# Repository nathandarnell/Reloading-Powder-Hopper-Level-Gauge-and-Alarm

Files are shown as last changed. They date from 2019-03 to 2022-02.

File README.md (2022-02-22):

# Reloading Powder Hopper Level Gauge and Alarm

This was inspired by a video by Farrow Tech: [https://www.youtube.com/watch?v=m2Si6LQx2WA](https://www.youtube.com/watch?v=m2Si6LQx2WA).  The demonstration it is about two years old and I haven't seen anything else like it so I decided to make my own version.  

## Hardware
My version uses an ESP8266 NodeMCU, a ST7735S TFT display, a VL6180X time of flight sensor, a rotary encoder, and some various hardware.
  * [NodeMCU ESP8266](https://www.ebay.com/itm/NodeMCU-Lua-ESP8266-ESP-12E-cp2102-Arduino-compatible-wifi-development-board/123866319935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) - The case is designed to fit this particular board. If you use a different size/shape board or one with different pin definitions it may not work correctly. The two main versions of these boards have either a CP2102 or CH340G chip. The CP2102 boards are narrower and what fits in this case so make sure you buy one of those!
  * [1.77" TFT Screen](https://www.ebay.com/itm/1-77-inch-1-8-TFT-Color-Display-Module-Breakout-SPI-ST7735S-for-Arduino-UNO-LCD/222565215470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) - This particular screen seems to be sold very widely and if you use the same pins to wire it and use the same settings in User_Setup.h for the TFT_eSPI library, it should work fine
  * [VL6180X Time-of-Flight Sensor](https://www.ebay.com/itm/For-Arduino-I2C-Gesture-Recognition-Range-Finder-Optical-Sensor-Module-VL6180X/302991764658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) - The Adafruit version of this sensor also seems to work correctly but is about 2x the cost
  * [Rotary Encoder](https://www.amazon.com/gp/product/B07BN3DGBS/ref=ppx_yo_dt_b_asin_title_o02_s00?ie=UTF8&psc=1) - See below for notes on what rotary encoders work well
  * [Buzzer](https://www.amazon.com/gp/product/B07VSHHFKJ/ref=ppx_yo_dt_b_search_asin_title?ie=UTF8&psc=1) - Optional buzzer if you want an audible cue that when the powder is low
  * 6 M3 nuts
  * 2 M2.5 nuts
  * 6 M3 x 10 screws
  * 2 M2.5 x 10 screws
  
## Libraries and firware.bin
While Farrow Tech was able to make it without libraries, mine uses:
  * [ArduinoMenu](https://github.com/neu-rah/ArduinoMenu)
  * [streamFlow](https://github.com/neu-rah/streamFlow)
  * [TFT_eSPI](https://github.com/Bodmer/TFT_eSPI) - You will have to setup your TFT settings in the User_Setup.h file.  I have included mine if you would like to copy it into the TFT_eSPI library folder.  If you use the library I included it is already correct
  * [VL6180X](https://github.com/pololu/vl6180x-arduino)
  * [ClickEncoder](https://github.com/soligen2010/encoder) - This is a fork of the rotary encoder library ArduinoMenu uses by default and has some updates over the original
  * [ardunoWebSockets](https://github.com/Links2004/arduinoWebSockets) - This library is needed by newer versions of ArduinoMenu even though it doesn't do anything for this program
  
### Adruino IDE esp8266 Board Version
As per [the comment from dandekalb](https://www.thingiverse.com/thing:3485453/comments#comment-6370874), you will get compile errors from the Arduino IDE if you have the board version set above 2.7.3.  This has not been tested on VS Code with PlatformIO but it is safe to assume the same.

To change the board version in Arduino IDE:

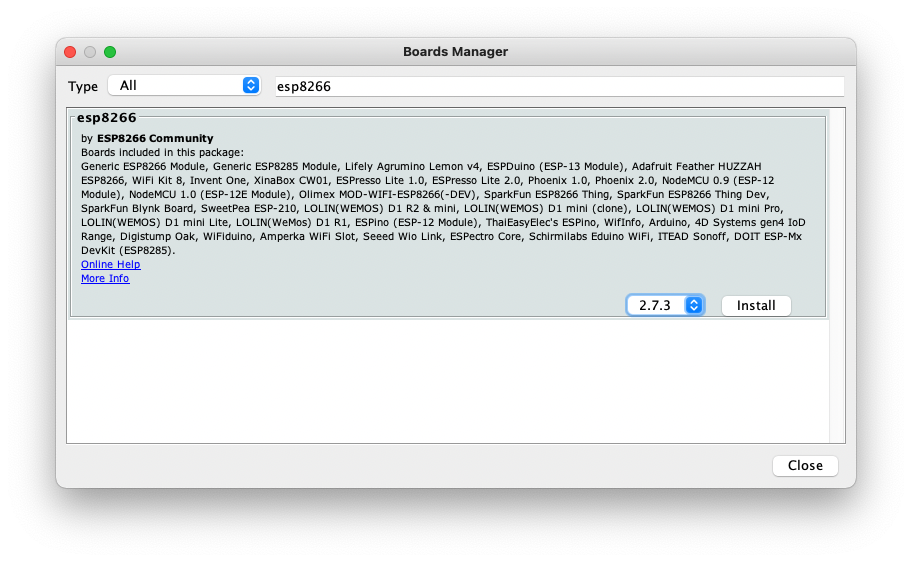
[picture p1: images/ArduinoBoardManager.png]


To change the board version in PlatformIO (this has not been tested but should work): 

In your platformi.ini replace

`platform = espressif8266`

with

`platform = espressif8266@2.7.3`

### Importing Libraries
Because some of the libraries (mostly ArduinoMenu) are under active development, I have downloaded the versions that work currently (9/4/2019) as zip files for importing into Arduino IDE or PlatformIO.  For Arduino there is a import a zip file to library menu option.  For PlatformIO with VS Code extract the zip files to the include folder within the project folder.  

### firmware.bin
If you are running into problems and have all of the wiring done like described in PowderHopperGauge.ino, I also uploaded a firmware.bin file that can be uploaded with [nodemcu-pyflasher](https://github.com/marcelstoer/nodemcu-pyflasher/releases) without the need to import libraries or compile anything yourself.  If you make changes to your wiring however, you will need to compile the program and the firmware.bin file will not work for you.

New for this version is the inclusion of the serial interface.  If you are having issues with the click encoder rotations not registering but the clicks are working, you can use the serial interface to navigate the ArduinoMenu options.

## Rotary Encoders
The most difficult troubleshooting seems to be with rotary encoders.  I have tried four different kinds and have found success with two of them.  There are two seperate issues that have come up: how the rotary encoder counts pulses and how the circuit uses pullups and capacitors.
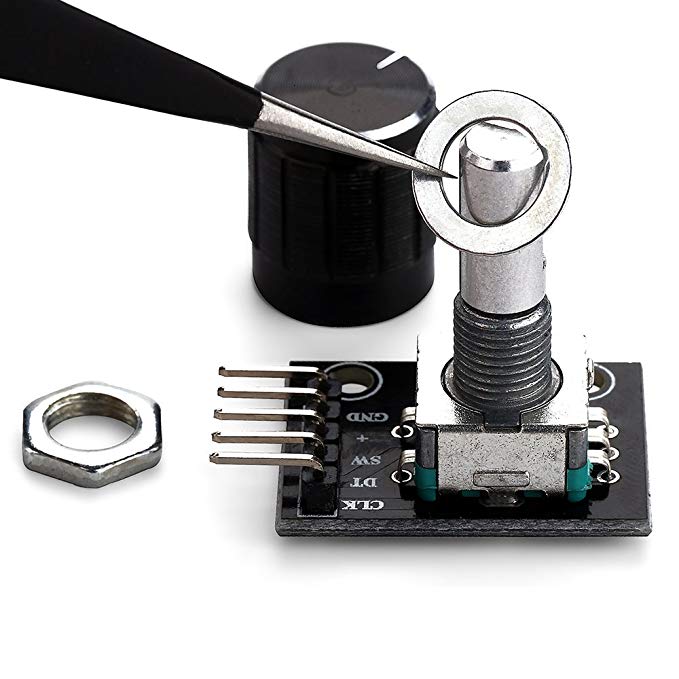
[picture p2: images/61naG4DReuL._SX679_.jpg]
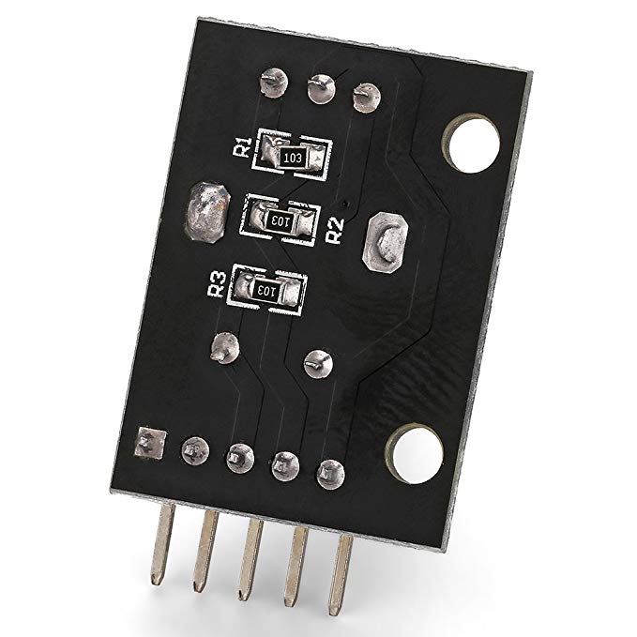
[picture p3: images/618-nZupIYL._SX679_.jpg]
  *  [Amazon 6 pack](https://www.amazon.com/gp/product/B07BN3DGBS/ref=ppx_yo_dt_b_asin_title_o02_s00?ie=UTF8&psc=1) - These have pullup resistors on the button and on the rotary encoder and mostly worked correctly.  Out of the six I received one did not work at all and one had at least a single deadspot that didn't register rotations.  Otherwise the price and consistancy has been good.
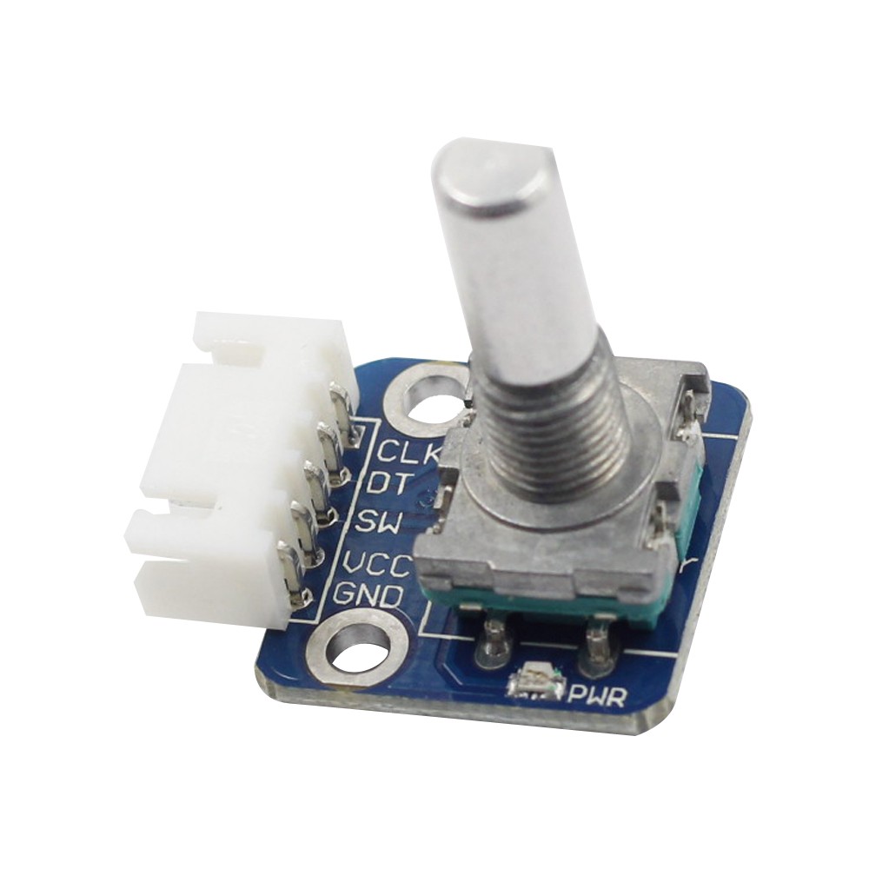
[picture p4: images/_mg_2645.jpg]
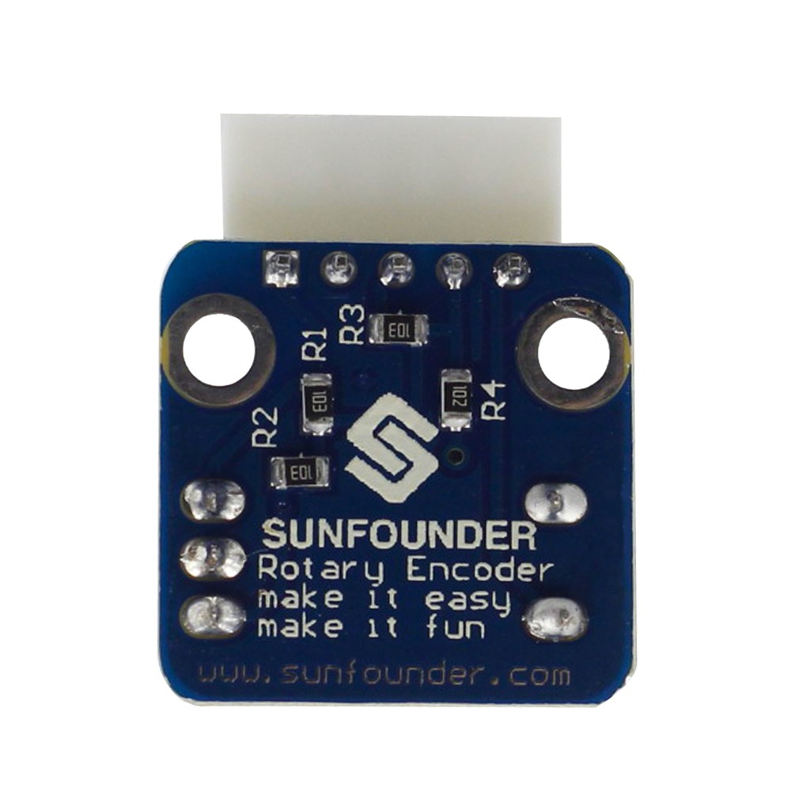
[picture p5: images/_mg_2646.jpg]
  *  [Sunfounder Rotary Encoder](https://www.sunfounder.com/rotary-encoder-module.html) - These also have pullups on all the pins as well as a LED so you can tell when it's powered on.  These are the most expensive option ($6.99 each) but the quality of the encoder and the board is very good.
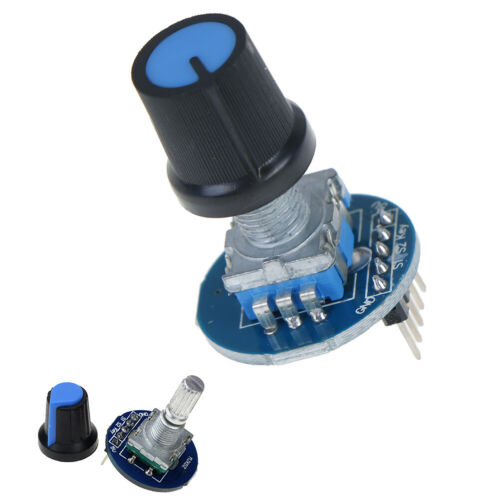
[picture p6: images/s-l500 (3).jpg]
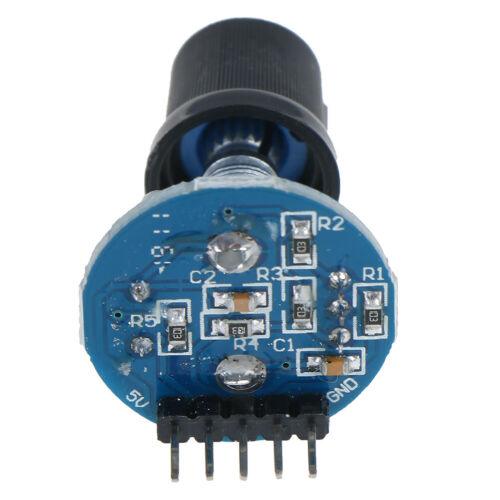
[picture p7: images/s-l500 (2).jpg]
  *  [Round PCB with capacitors for 5V](https://www.ebay.com/itm/Rotary-encoder-module-brick-sensor-development-audio-potentiometer-knob-SKUS/233308683253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) - These seem like a great option since they have capacitors for debouncing but they only work correctly with 5V and will not work at 3.3V.  They seem easy to distinguish since the power pins are labeled "5V" and not "VIN" or "+" like the others here.  And they are round.  I haven't seen any that look like this one that do not say "5V" on them so I would steer clear.
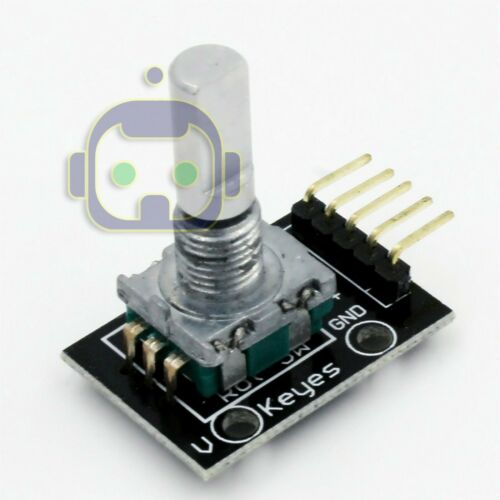
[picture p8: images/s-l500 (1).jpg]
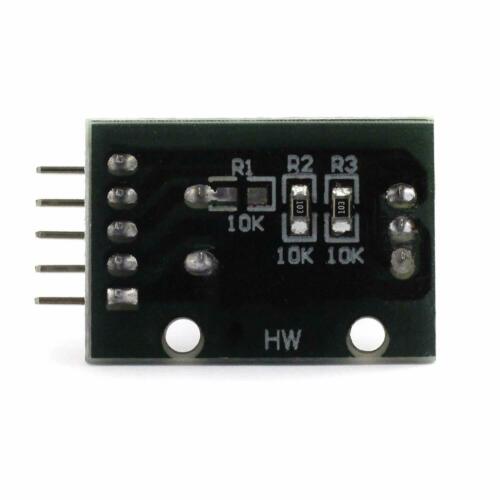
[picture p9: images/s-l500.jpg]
  *  [Half step wth no switch pullup](https://www.ebay.com/itm/2X-Rotary-Encoder-Digital-Potentiometer-20mm-Knurled-Shaft-with-Switch-USA/382606587878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) - This one has two issues: the switch doesn't have pullups on it like the others above but the deal breaker is that the rotary encoder outputs half the pulses of the other models.  Each "click" moves both pins to high or both pins to low.  The others move both pins to low and high on every "click."

## Rotary Encoder Testing
From bristolwatch.com, a diagram of what the rotary encoder should do for each "click" (the dashed vertical lines are each a detent that the encoder stops in):

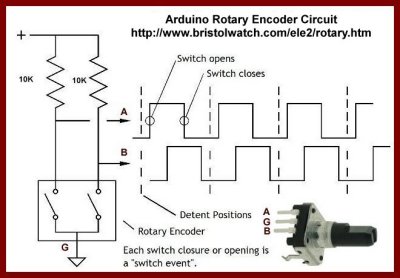
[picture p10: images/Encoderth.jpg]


I wrote a simple sketch to output the voltage of each pin the encoders are wired to.  It is from some code by [Random Nerd Tutorials](https://randomnerdtutorials.com/esp32-adc-analog-read-arduino-ide/) and adjusted for rotary encoders.  It needs an ESP32 and the encoder needs to have the CLK and DT pins on any of these red-highlighted pins: 

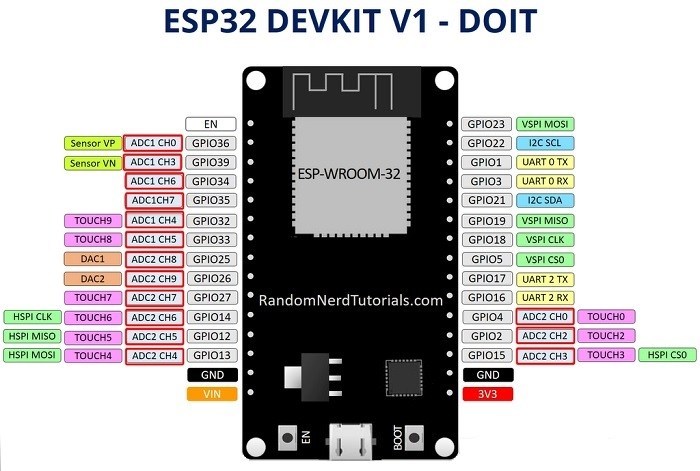
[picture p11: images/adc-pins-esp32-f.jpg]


Once you upload and run it, the serial monitor will tell you the voltage of each of the two pins.  As you rotate the encoder slowly, you can see what each one does.  Ideally, they should both start high (4095 on ESP32) and as you rotate one will drop to low (0) followed by the second pin, then both will go to high one after the other in the same order as you finish the click.  Rotating slowly the opposite direction should show the leading pin is now the trailing pin going low and high.  The half step encoder shown above only does half of that each click and so it doesn't work reliably with the ClickEncoder library (menu selection will jump down and then back up with each click).

## Building and Wiring
Use a breadboard and jumper wires to make sure everything is wired correctly and test the sketch.  

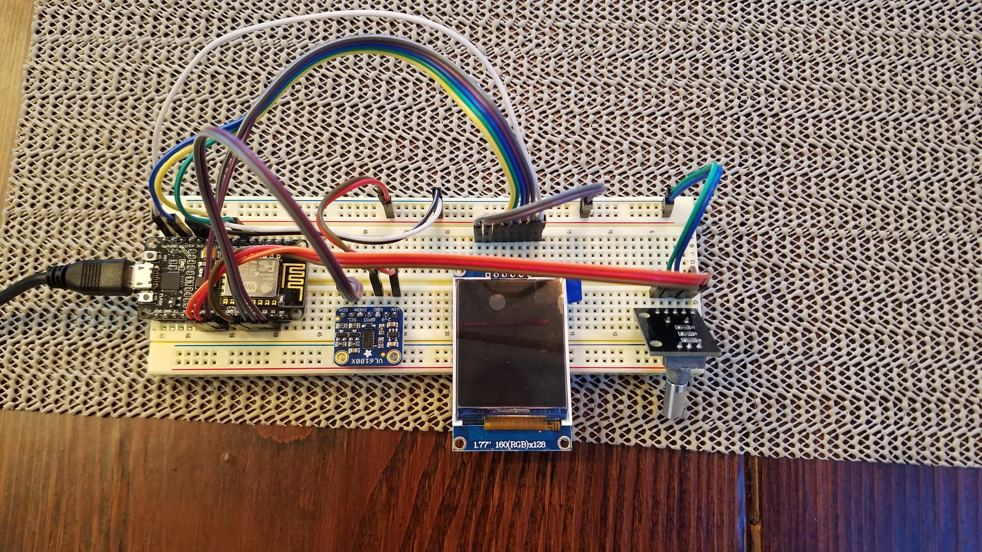
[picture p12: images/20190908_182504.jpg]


When you are ready to install it in the enclosure, use jumpers between the VL6180X sensor and the ESP8266, desolder the pins on the TFT and Rotary Encoder and directly solder the jumper wires from the ESP8266 onto each.  I used some hot glue to protect the connections and provide some strain reliefe on them.  

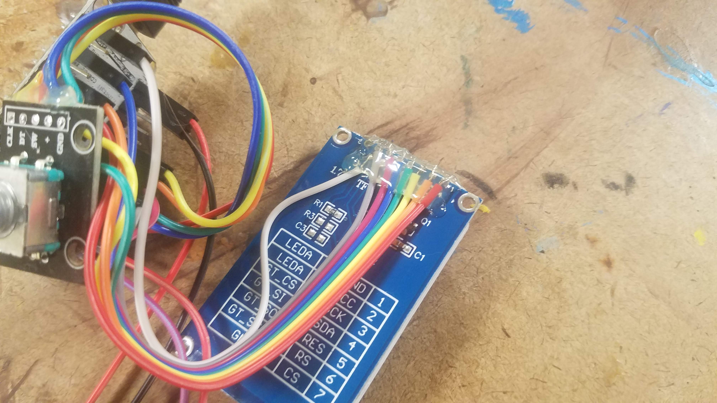
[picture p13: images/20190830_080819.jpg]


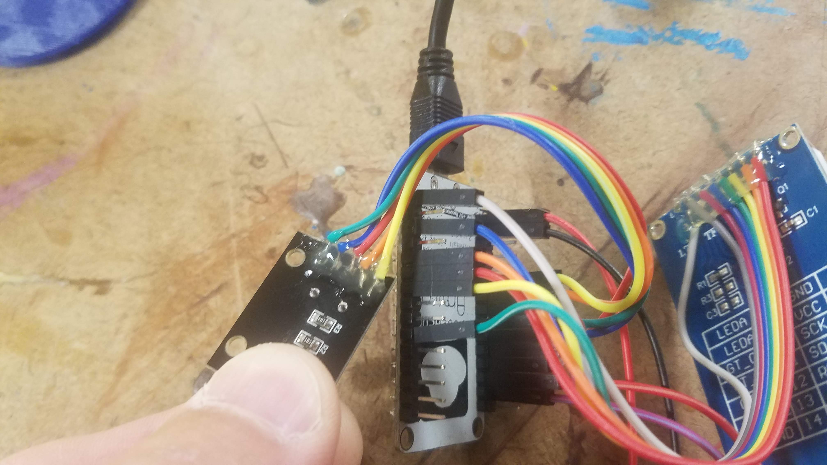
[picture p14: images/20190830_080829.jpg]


Install the four 3mm nuts in the enclosure.  Lower the assembly from the top and slide the TFT and ESP8266 into their slots and then install the VL6180X to the bottom cover.  **Optional** If you are using the version with the buzzer, lower the buzzer and install it in the hole (it should be a tight press fit) as you slide the assembly in.  I found some hot glue around the edges kept the sensor nice and level when securing it down to the base with screws.  

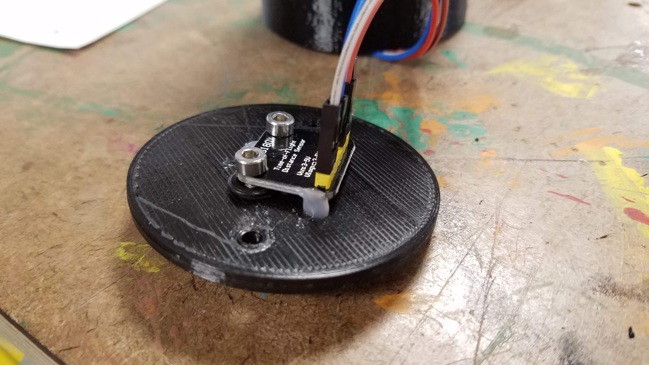
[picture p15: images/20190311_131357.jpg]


Screw the bottom cover in place.

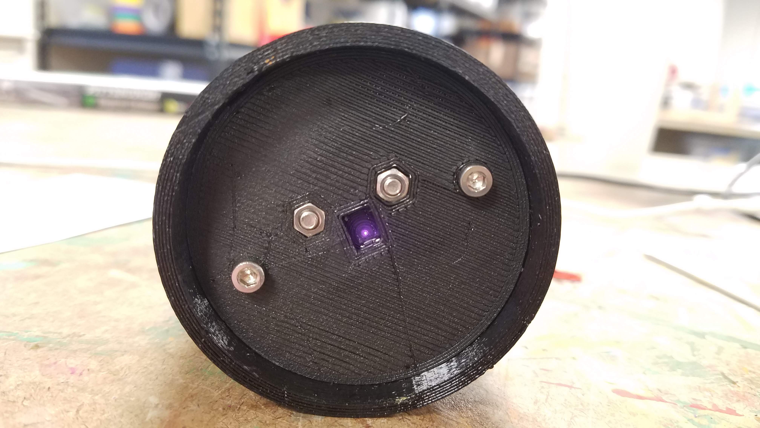
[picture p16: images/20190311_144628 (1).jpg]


Next install the screen's 2.5mm screws and nuts and the rotary encoder to the top cover.  Last, install the top.  The fit is tight so I suggest testing to make sure all the connections are still secure as you do each step.

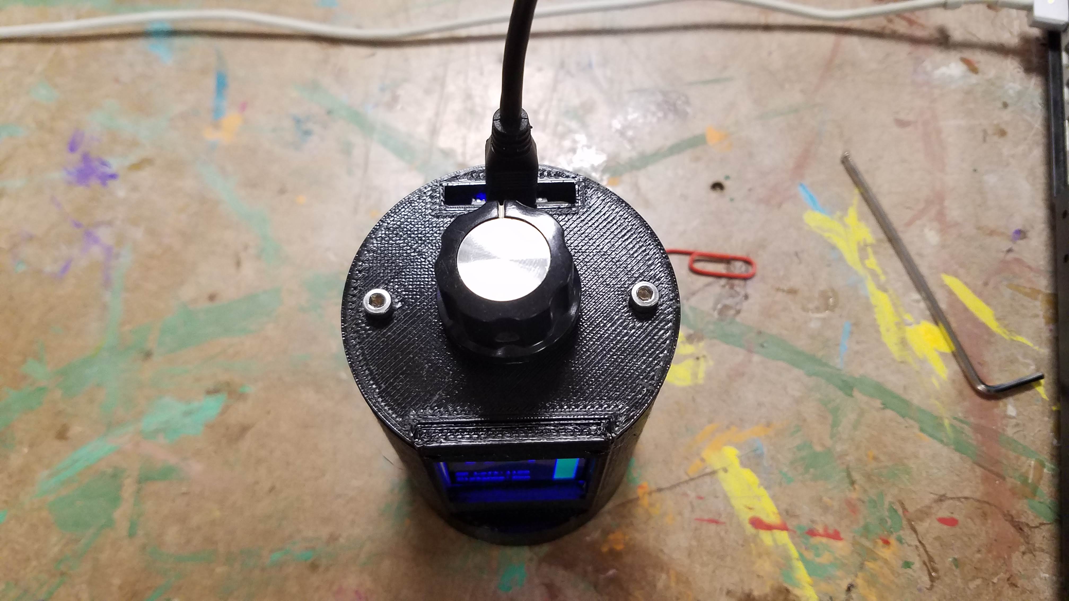
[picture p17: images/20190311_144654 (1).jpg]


## Adjusting to Your Needs
The STL is included for the Hornady Powder Hopper as well as the Dillon and the original design file is on Onshape if you want to make a copy and adjust the design for another brand of powder hopper: [Onshape Design](https://cad.onshape.com/documents/c187c6855e5b717b6eb50d9e/w/ed8cc32766a24fa2c6d4d2bb/e/9d09fd4bb0b1d438497f7fdc)

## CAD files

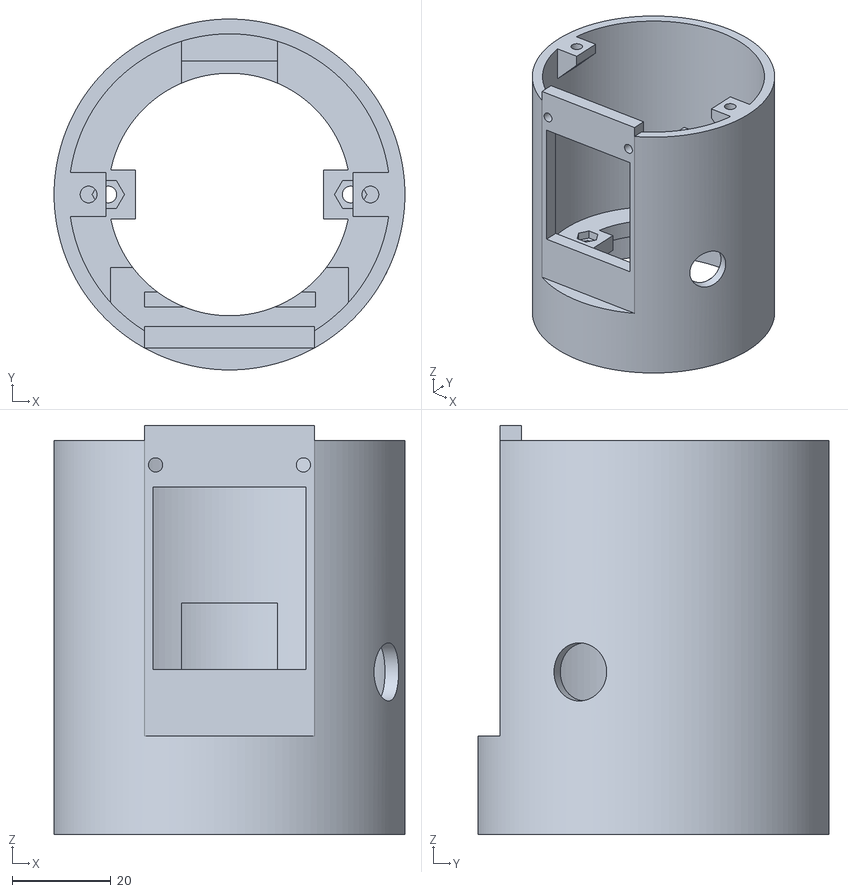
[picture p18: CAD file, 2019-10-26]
STLs/Dillon Main Body with Buzzer V1.4.stl
71.2 x 71.2 x 83.0

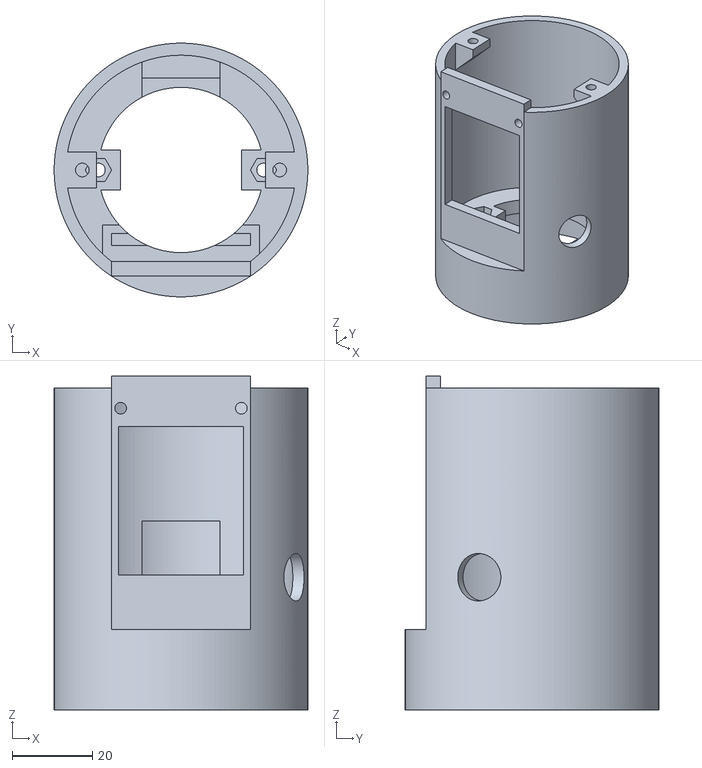
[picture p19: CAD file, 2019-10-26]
STLs/Hornady Main Body with Buzzer V1.4.stl
63.1 x 63.1 x 83.0

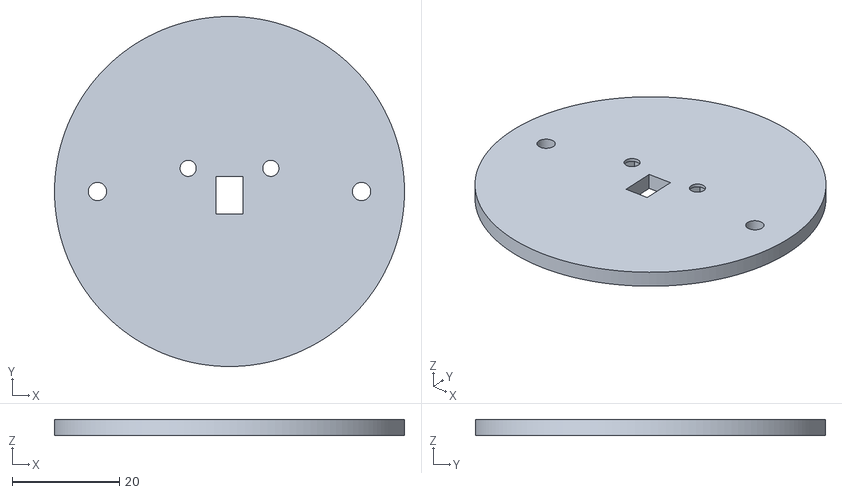
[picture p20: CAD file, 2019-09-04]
STLs/Dillon_Bottom_V1.stl
65.2 x 65.2 x 3.00

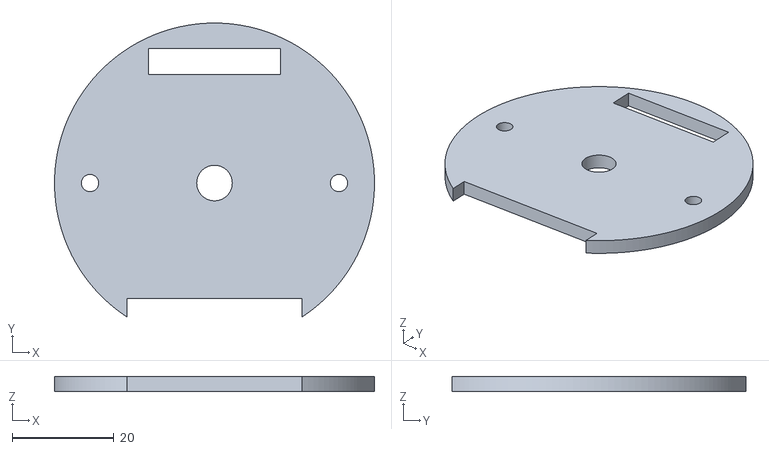
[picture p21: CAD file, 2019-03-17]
STLs/Cover V1.3.stl
63.0 x 57.9 x 3.00

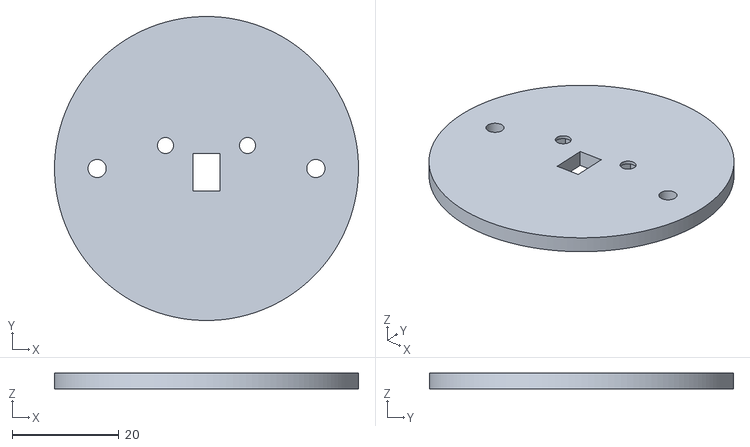
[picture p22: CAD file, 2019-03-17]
STLs/Bottom V1.3.stl
57.0 x 57.0 x 3.00

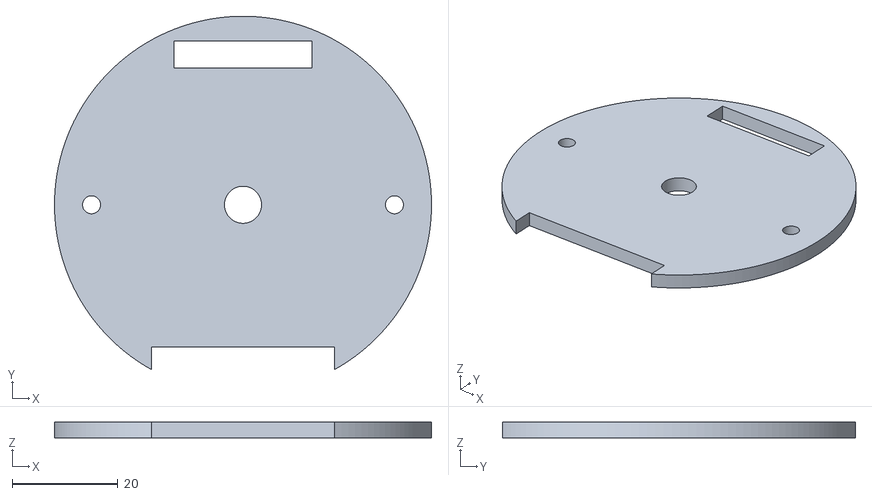
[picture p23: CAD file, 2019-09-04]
STLs/Dillon_Screw_on_Cover_V1.stl
71.2 x 66.7 x 3.00

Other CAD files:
STLs/Dillon_Main_Body_V1.1.stl
STLs/Main Body V1.3.stl

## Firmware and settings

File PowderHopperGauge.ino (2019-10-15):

extern "C"
{ //esp8266 stuff
#include "user_interface.h"
}
#include <menu.h>
#include <menuIO/serialIO.h>
#include <menuIO/esp8266Out.h>
#include <menuIO/clickEncoderIn.h>
#include <menuIO/chainStream.h>
#include <menuIO/TFT_eSPIOut.h> // Edit User_Setup.h in TFT_eSPI folder for your setup
#include <streamFlow.h>         // https://github.com/neu-rah/streamFlow
#include <Ticker.h>
#include <ClickEncoder.h> // https://github.com/soligen2010/encoder
#include <TFT_eSPI.h>     // https://github.com/Bodmer/TFT_eSPI
#include <VL6180X.h>      // https://github.com/pololu/vl6180x-arduino
#include <Wire.h>
#include <EEPROM.h>

// TFT Wiring:
//
// SainSmart   ESP8266    Description
//   Names      Pins
//
//  GND  1      GND       // Obvious
//  VCC  2      3V3       // Obvious
//  SCK  3      CLK       // Must be CLK when TFT_SPI_OVERLAP is defined
//  SDA  4      SD1       // Must be SD1 when TFT_SPI_OVERLAP is defined
//  RES  5      RST       // Could be on GND when RST is set to -1
//  RS   6      D5        // Could be another open pin
//  CS   7      D3        // Must be D3 when TFT_SPI_OVERLAP is defined
//  LEDA 8      VIN       // Might need to be on 3.3v but I have been running it on VIN 5V YMMV

// Rotary Encoder Wiring:
//
// KY-040     ESP8266    Description
//  Pins       Pins
//
//  GND        GND       // Obvious
//  +          3V3       // Obvious
//  SW         D4        // Could be any good input pin
//  DT         D6        // Could be any good input pin
//  CLK        D7        // Could be any good input pin

// VL6180X Wiring:
//
// VL6180X     ESP8266    Description
//   Pins       Pins
//
//  VIN         3V3       // Obvious
//  GND         GND       // Obvious
//  SCL         D1        // Hardcoded on ESP8266 so must be D1
//  SDA         D2        // Hardcoded on ESP8266 so must be D2

// Alarm Buzzer Wiring:
//
//  Buzzer     ESP8266    Description
//   Wire       Pins
//
//  Red         D8       // Could be any good input pin *EXCEPT GPIO 3 or 11*
//  Black       GND      //  Wire a 100 ohm resistor inline betwen the buzzer and the gnd

using namespace Menu;

// No need to declare pins for 6180 sensor if you use the standard pins on ESP8266
//SDA=4 => D2.
//SCL=5 => D1

// Define pins for rotary encoder
// Corresponds to the GPIO For the Pin
// Google Image Search "ESP8266 Pinout" 
#define encA 12
#define encB 13
#define encBtn 2
#define encSteps 4

// Declare the clickEncoder
ClickEncoder clickEncoder(encA, encB, encBtn, encSteps);
ClickEncoderStream encStream(clickEncoder, 1);

// Start the serial input for ArduinoMenu
serialIn serial(Serial);

// Declare the timer
Ticker ticker;

// Declare the TFT
TFT_eSPI gfx = TFT_eSPI();

// Declare the distance sensor
VL6180X sensor;

// Define the width and height of the TFT and how much of it to take up
#define GFX_WIDTH 160
#define GFX_HEIGHT 128
#define fontW 6
#define fontH 9

// Setup TFT colors
#define SCALECOLOR TFT_WHITE
#define BACKCOLOR TFT_BLACK
#define BARCOLOR TFT_GREEN
#define ALERTCOLOR TFT_RED
#define TEXTCOLOR TFT_WHITE

//Specify GPIO of pin that the positive lead of piezo buzzer is attached.
int piezoPin = 15;

// Bar gragh size and position
int barWidth = 20;
float barHeight = 144.0;
int barX = 100;
int barY = 8;

// Measurement Declarations for Sensor
int alarmEnabled = 1;
int rawValue = 20; // Measurement from the sensor in mm
int minDist = 20;  // The closest reading to the sensor in mm: 100% full
int maxDist = 120; // The furthest reading from the sensor in mm: 0% full
int lastPercent = 0;
int newPercent;
int alertPercent = 20;
int grainsPerMM = 12;
int grainsLeft = 0;
int grainsAdded = 50; // For measuring grains per mm
int grainsAddedStart = 0;
int grainsAddedFinish = 0;
int alertPercentGrains = 0;

// 

// For saving some variables to EEPROM, only need minDist, maDist, alertPercent, and grainsPerMM
// TODO form into struct: https://github.com/esp8266/Arduino/issues/1053
#define MIN_DIST_ADDR 0
#define MAX_DIST_ADDR MIN_DIST_ADDR + sizeof(int)
#define ALERT_PERCENT_ADDR MAX_DIST_ADDR + sizeof(int)
#define GRAINS_PER_MM_ADDR ALERT_PERCENT_ADDR + sizeof(int)
#define ALARM_BUZZER_ADDR GRAINS_PER_MM_ADDR + sizeof(int)

// Strings for displaying text
String textRawSensorValue = "Distance:";
String textGrainsLeft = "GR Left:";

// Define the number of samples to keep track of. The higher the number, the
// more the readings will be smoothed, but the slower the output will respond to
// the input. Using a constant rather than a normal variable lets us use this
// value to determine the size of the readings array.
// 10 seemed too fast
const int numReadings = 35;

int readings[numReadings]; // the readings from the sensor input
int readIndex = 0;         // the index of the current reading
int total = 0;             // the running total
int average = 0;           // the average

int drawOverlayField = 0; //change this when you click a certain prompt
bool buttonPressed = 0;
int aPer = 0;
int lastAPer = 1000;
int *editField;

// Function definitions
void doDrawOverlayField(int min, int max);
int checkEEPROM(int ADDR, int value, int min, int max);
void readSensor();
void writeToScreen();
void drawScale();
void drawBar(float nPer);
void writePercentText(int nPer);
void writeSensorValues(int sensorValue);
void ICACHE_RAM_ATTR timerIsr()
{
  clickEncoder.service();
}

//////////////////////////////////////////////////////////
// Start ArduinoMenu
//////////////////////////////////////////////////////////
result saveEEPROMQuit()
{
  EEPROM.commit();
  return quit;
}

result rebootESP()
{
  delay(1000);
  ESP.restart();
  return proceed;
}

result setGrainsSave()
{
  Serial.print("Writing to EEPROM location: ");
  Serial.println(GRAINS_PER_MM_ADDR);
  Serial.print("Writing: ");
  Serial.println(grainsPerMM);
  EEPROM.put(GRAINS_PER_MM_ADDR, grainsPerMM);
  EEPROM.commit();
  return quit;
}

result alertPercentSave()
{
  Serial.print("Writing to EEPROM location: ");
  Serial.println(ALERT_PERCENT_ADDR);
  Serial.print("Writing: ");
  Serial.println(alertPercent);
  EEPROM.put(ALERT_PERCENT_ADDR, alertPercent);
  EEPROM.commit();
  return quit;
}

result alarmEnabledSave()
{ 
  Serial.print("Writing to EEPROM location: ");
  Serial.println(ALARM_BUZZER_ADDR);
  Serial.print("Writing: ");
  Serial.println(alarmEnabled);
  EEPROM.put(ALARM_BUZZER_ADDR, alarmEnabled);
  EEPROM.commit();
  return quit;
}

result measureGrainsStart(eventMask e)
{
  grainsAddedStart = rawValue;
  return proceed;
}

result measureGrainsAdded(eventMask e)
{
  grainsAddedFinish = rawValue;
  grainsPerMM = grainsAdded / (grainsAddedStart - grainsAddedFinish);
  Serial.print("Writing to EEPROM location: ");
  Serial.println(GRAINS_PER_MM_ADDR);
  Serial.print("Writing: ");
  Serial.println(grainsPerMM);
  EEPROM.put(GRAINS_PER_MM_ADDR, grainsPerMM);
  return proceed;
}

result measureMinLevel(eventMask e)
{
  maxDist = rawValue;
  Serial.print("Writing to EEPROM location: ");
  Serial.println(MAX_DIST_ADDR);
  Serial.print("Writing maxDist: ");
  Serial.println(maxDist);
  EEPROM.put(MAX_DIST_ADDR, maxDist);
  return proceed;
}

result measureMaxLevel(eventMask e)
{
  minDist = rawValue;
  Serial.print("Writing to EEPROM location: ");
  Serial.println(MIN_DIST_ADDR);
  Serial.print("Writing minDist: ");
  Serial.println(minDist);
  EEPROM.put(MIN_DIST_ADDR, minDist);
  return proceed;
}

result showEvent(eventMask e, navNode &nav, prompt &item)
{
  Serial.print("event: ");
  Serial.println(e);
  return proceed;
}

result editAlarmLevel()
{
  drawOverlayField = 1;
  delay(500);
  return proceed;
}

result editGrainsPerMM()
{
  drawOverlayField = 2;
  delay(500);
  return proceed;
}

MENU(subMenuAlertPercent, "Set Alarm Level", showEvent, noEvent, noStyle, OP("Edit Alarm Level", editAlarmLevel, enterEvent), FIELD(alertPercentGrains, "Alarm in GR:", "GR", 0, 10000, 10, 1, doNothing, noEvent, noStyle), OP("<Save to EEPROM", alertPercentSave, enterEvent), EXIT("<Back"));

MENU(subMenuCalibrate, "Calibrate Height", showEvent, noEvent, noStyle, FIELD(rawValue, "Current Dist:", "mm", 0, 255, 10, 1, NULL, enterEvent, noStyle), OP("Measure Empty Level", measureMinLevel, enterEvent), OP("Measure Full Level", measureMaxLevel, enterEvent), FIELD(maxDist, "Empty Level:", "mm", 0, 255, 10, 1, doNothing, noEvent, noStyle), FIELD(minDist, "Full Level:", "mm", 0, 255, 10, 1, doNothing, noEvent, noStyle), OP("<Save to EEPROM", saveEEPROMQuit, enterEvent), EXIT("<Back"));

MENU(subMenuMeasureGrains, "Measure Grains/mm", showEvent, noEvent, wrapStyle, FIELD(rawValue, "Current Dist:", "mm", 0, 255, 10, 1, NULL, enterEvent, noStyle), FIELD(grainsAdded, "Grains to Add:", "GR", 0, 250, 10, 1, doNothing, noEvent, noStyle), OP("Measure Low Distance", measureGrainsStart, enterEvent), OP("Measure High Distance", measureGrainsAdded, enterEvent), FIELD(grainsAddedStart, "Starting Distance:", "mm", 0, 255, 10, 1, doNothing, noEvent, noStyle), FIELD(grainsAddedFinish, "Finish Distance:", "mm", 0, 255, 10, 1, doNothing, noEvent, noStyle), OP("<Save to EEPROM", saveEEPROMQuit, enterEvent), EXIT("<Back"));

MENU(subMenuSetGrains, "Set Grains/mm", showEvent, noEvent, noStyle, OP("Set Grains/mm", editGrainsPerMM, enterEvent), FIELD(grainsPerMM, "Grains/mm:", "GR/mm", 0, 100, 10, 1, doNothing, noEvent, noStyle), OP("<Save to EEPROM", setGrainsSave, enterEvent), EXIT("<Back"));

CHOOSE(alarmEnabled, alarmBuzzerChoose, "Alarm Buzzer:", doNothing, noEvent, noStyle, VALUE("On", 1, doNothing, noEvent), VALUE("Off", 0, doNothing, noEvent));

MENU(subMenuAlarmBuzzer, "Alarm Buzzer On/Off", showEvent, noEvent, noStyle, SUBMENU(alarmBuzzerChoose), OP("<Save to EEPROM", alarmEnabledSave, enterEvent),EXIT("<Back"));

MENU(mainMenu, "POWDER LEVEL SENSOR", doNothing, noEvent, wrapStyle, SUBMENU(subMenuCalibrate), SUBMENU(subMenuAlertPercent), SUBMENU(subMenuMeasureGrains), SUBMENU(subMenuSetGrains), SUBMENU(subMenuAlarmBuzzer), EXIT("Exit Menu"));

#define MAX_DEPTH 3

// define menu colors-- ------------------------------------------------------
#define Black RGB565(0, 0, 0)
#define Red RGB565(255, 0, 0)
#define Green RGB565(0, 255, 0)
#define Blue RGB565(0, 0, 255)
#define Gray RGB565(128, 128, 128)
#define LighterRed RGB565(255, 150, 150)
#define LighterGreen RGB565(150, 255, 150)
#define LighterBlue RGB565(150, 150, 255)
#define LighterGray RGB565(211, 211, 211)
#define DarkerRed RGB565(150, 0, 0)
#define DarkerGreen RGB565(0, 150, 0)
#define DarkerBlue RGB565(0, 0, 150)
#define Cyan RGB565(0, 255, 255)
#define Magenta RGB565(255, 0, 255)
#define Yellow RGB565(255, 255, 0)
#define White RGB565(255, 255, 255)
#define DarkerOrange RGB565(255, 140, 0)

// TFT color table
const colorDef<uint16_t> colors[] MEMMODE = {
    //{{disabled normal,disabled selected},{enabled normal,enabled selected, enabled editing}}
    {{(uint16_t)Black, (uint16_t)Black}, {(uint16_t)Black, (uint16_t)Red, (uint16_t)Red}},     //bgColor
    {{(uint16_t)White, (uint16_t)White}, {(uint16_t)White, (uint16_t)White, (uint16_t)White}}, //fgColor
    {{(uint16_t)Red, (uint16_t)Red}, {(uint16_t)Yellow, (uint16_t)Yellow, (uint16_t)Yellow}},  //valColor
    {{(uint16_t)White, (uint16_t)White}, {(uint16_t)White, (uint16_t)White, (uint16_t)White}}, //unitColor
    {{(uint16_t)White, (uint16_t)Gray}, {(uint16_t)Black, (uint16_t)Red, (uint16_t)White}},    //cursorColor
    {{(uint16_t)White, (uint16_t)Yellow}, {(uint16_t)Black, (uint16_t)Red, (uint16_t)Red}},    //titleColor
};

constMEM panel panels[] MEMMODE = {{0, 0, GFX_WIDTH / fontW, GFX_HEIGHT / fontH}}; // Main menu panel
navNode *nodes[sizeof(panels) / sizeof(panel)];                                    //navNodes to store navigation status
panelsList pList(panels, nodes, sizeof(panels) / sizeof(panel));                   //a list of panels and nodes
idx_t eSpiTops[MAX_DEPTH] = {0};
TFT_eSPIOut eSpiOut(gfx, colors, eSpiTops, pList, fontW, fontH + 1);
idx_t serialTops[MAX_DEPTH] = {0};
serialOut outSerial(Serial, serialTops);
menuOut *constMEM outputs[] MEMMODE = {&eSpiOut, &outSerial};  //list of output devices
outputsList out(outputs, sizeof(outputs) / sizeof(menuOut *)); //outputs list
MENU_INPUTS(in, &encStream, &serial);                          // removed: &encButton,
NAVROOT(nav, mainMenu, MAX_DEPTH, in, out);

void setup()
{
  pinMode(encBtn, INPUT_PULLUP); // Was: INPUT_PULLUP but already has pullup resistor on it

  clickEncoder.setAccelerationEnabled(true);
  clickEncoder.setButtonOnPinZeroEnabled(true);
  clickEncoder.setButtonHeldEnabled(true);
  clickEncoder.setDoubleClickEnabled(false);

  delay(500);
  Serial.begin(115200);
  while (!Serial)
    ;
  Serial.println("Booting");
  delay(1000);
  Serial.flush();

  // STart the TFT
  gfx.init();
  gfx.setRotation(0);
  gfx.fillScreen((uint16_t)Black);

  // Start the VL6180X
  Wire.begin();
  sensor.init();
  sensor.configureDefault();
  sensor.setTimeout(500);

  // initialize all the readings from the VL6180x to 0
  for (int thisReading = 0; thisReading < numReadings; thisReading++)
  {
    readings[thisReading] = 0;
  }

  // commit 512 bytes of ESP8266 flash (for "EEPROM" emulation)
  // this step actually loads the content (512 bytes) of flash into
  // a 512-byte-array cache in RAM
  EEPROM.begin(512);
  Serial.println("Starting EEPROM");
  // Read values from EEPROM into the variables if they fit in the min-max range
  minDist = checkEEPROM(MIN_DIST_ADDR, minDist, 0, 250);
  maxDist = checkEEPROM(MAX_DIST_ADDR, maxDist, 0, 250);
  alertPercent = checkEEPROM(ALERT_PERCENT_ADDR, alertPercent, 0, 100);
  grainsPerMM = checkEEPROM(GRAINS_PER_MM_ADDR, grainsPerMM, 0, 100);
  alarmEnabled = checkEEPROM(ALARM_BUZZER_ADDR, alarmEnabled, 0, 1);

  subMenuCalibrate[0].enabled = disabledStatus;     // Disables the first item in the subMenuCalibrate
  subMenuCalibrate[3].enabled = disabledStatus;     // Disables the third item in the subMenuCalibrate
  subMenuCalibrate[4].enabled = disabledStatus;     // Disables the fourth item in the subMenuCalibrate
  subMenuMeasureGrains[0].enabled = disabledStatus; // Disables the first item in the subMenuMeasureGrains
  subMenuMeasureGrains[4].enabled = disabledStatus; // Disables the fourth item in the subMenuMeasureGrains
  subMenuMeasureGrains[5].enabled = disabledStatus; // Disables the fifth item in the subMenuMeasureGrains
  subMenuAlertPercent[1].enabled = disabledStatus;  // Disables the second item in the subMenuAlertPercent
  subMenuSetGrains[1].enabled = disabledStatus;     // Disables the second item in the subMenuSetGrains

  nav.showTitle = true; // Show titles in the menus and submenus
  nav.timeOut = 60;     // Timeout after 60 seconds of inactivity and return to the sensor read screen
  nav.idleOn();         // Start with the main screen and not the menu

  ticker.attach(0.001, timerIsr);
}

void loop()
{
  // Slow down the menu redraw rate
  constexpr int menuFPS = 1000 / 30;
  static unsigned long lastMenuFrame = -menuFPS;
  unsigned long now = millis();
  //... other stuff on loop, will keep executing

  switch (drawOverlayField)
  {
  case 1:
  {
    editField = &alertPercent;
    doDrawOverlayField(0, 100);
    break;
  }
  case 2:
  {
    editField = &grainsPerMM;
    doDrawOverlayField(0, 100);
    break;
  }
  default:
    if (now - lastMenuFrame >= menuFPS)
    {
      lastMenuFrame = millis();
      readSensor(); // Constantly read the sensor in and out of the menu
      nav.poll();   // Poll the input devices
      if (nav.sleepTask)
      {
        writeToScreen(); // If the menu system is not active, draw the main screen
      }
    }
  }
}

// Draw the alertPercent value passed onto the screen overwriting the menu until done
void doDrawOverlayField(int min, int max)
{
  char charAlertPercent[7];
  String paddingSpaces = "";
  String tempPercent = "";
  int alertPercentDrawX = 10;

  // Draw the value and background if the value has changed
  if (*editField != lastAPer)
  {                        // Replaced alertPercent
    lastAPer = *editField; //alertPercent;
    aPer = *editField;     //alertPercent;
    // Draw the background over the menu
    gfx.drawRect(9, 9, 110, 142, ALERTCOLOR);
    gfx.fillRect(10, 10, 108, 140, BACKCOLOR);

    // Keep the percent from dropping below 0% or over 100%
    if (aPer < min)
    {
      aPer = min;
    }
    if (aPer > max)
    {
      aPer = max;
    }

    // convert to a string
    String aPercent = String(aPer);

    // Pad the value with leading spaces to keep it right-aligned
    if (aPer < 10)
      paddingSpaces = "  ";
    else if (aPer < 100)
    {
      paddingSpaces = " ";
    }
    else
    {
      paddingSpaces = "";
    }

    // Append the percent symbol
    switch (drawOverlayField)
    {
    case 1:
    {
      aPercent += "%";
      break;
    }
    case 2:
    {
      aPercent += "gr";
      int paddingSpacesIndex = paddingSpaces.length() - 1;
      paddingSpaces.remove(paddingSpacesIndex);
      alertPercentDrawX = 20;
      break;
    }
    }

    tempPercent = paddingSpaces + aPercent;

    // add to an array
    tempPercent.toCharArray(charAlertPercent, 5);

    // Set size and color then print out the text
    gfx.setTextSize(4);
    gfx.setTextColor(ALERTCOLOR, BACKCOLOR);
    gfx.drawString(charAlertPercent, alertPercentDrawX, 50);
  }

  // Update the encoder and add it to alertPercent
  int encoderPos = clickEncoder.getValue();
  if (encoderPos != 0)
  {
    *editField += encoderPos;
  } // Replaced alertPercent

  // See if encoder button is open or closed to exit the menu
  // From ClickEncoder ESP8266Example.ino
  ClickEncoder::Button b = clickEncoder.getButton();
  if (b == ClickEncoder::Clicked)
    buttonPressed = 1;

  if (buttonPressed)
  {
    buttonPressed = 0;  // reset the button status so one press results in one action
    gfx.setTextSize(1); // Reset the text size so the menu looks right
    lastAPer = 1000;    // Reset lastAPer so it will always draw the next time it is run
    gfx.fillScreen((uint16_t)Black);
    drawOverlayField = 0;             // Set to false to get back to the menu
    delay(1000);                      // Pause for a second to not be pressing the button back in the menu
    subMenuAlertPercent.dirty = true; // Tell the submenu to redraw itself
    subMenuSetGrains.dirty = true;
    if (alarmEnabled)
    {
      noTone(piezoPin);
    }
    return;
  }
}

// Check each address in EEPROM if the values fit into the range passed, read them into memory
int checkEEPROM(int ADDR, int value, int min, int max)
{
  int tempEEPROM = EEPROM.read(ADDR);
  Serial.print("ADDR: ");
  Serial.println(ADDR);
  Serial.print("value: ");
  Serial.println(tempEEPROM);
  if (tempEEPROM >= min && tempEEPROM <= max)
  {
    return tempEEPROM;
  }
  else
  {
    return value;
  }
}

// Determine if the bar graph and displayed values need updating
void writeToScreen()
{
  if (newPercent != lastPercent)
  {
    writePercentText(newPercent);
    writeSensorValues(rawValue);
    drawBar(newPercent);
  }

  drawScale(); // Set to always draw the scale
}

// Smoothly grab the new reading from the sensor and average to smooth
void readSensor()
{
  // subtract the last reading:
  total = total - readings[readIndex];
  // read from the sensor:
  readings[readIndex] = sensor.readRangeSingleMillimeters();
  // add the reading to the total:
  total = total + readings[readIndex];
  // advance to the next position in the array:
  readIndex = readIndex + 1;

  // if we're at the end of the array...
  if (readIndex >= numReadings)
  {
    // ...wrap around to the beginning:
    readIndex = 0;
  }

  // calculate the average:
  average = total / numReadings;
  // send it to the computer as ASCII digits
  rawValue = average;
  //  delay(1);        // delay in between reads for stability

  // Calculate the percent based on the reading and the range of minDist and maxDist
  newPercent = ((maxDist - rawValue) * 100) / (maxDist - minDist);

  // Calculate the alet percent in grains value for the menu screen
  alertPercentGrains = (grainsPerMM * (maxDist - minDist) * alertPercent) / 100;

  // Debugging if the sensor isn't working correctly
  // Serial.println("rawValue: ");
  // Serial.println(rawValue);
  // Serial.println("newPercent: ");
  // Serial.println(newPercent);
  // delay(100);
}

// Draw the bar graph outline on the right of the main screen
// HEAVILY influenced by: http://henrysbench.capnfatz.com/henrys-bench/arduino-adafruit-gfx-library-user-guide/arduino-adafruit-gfx-bar-graph/
// and also: https://www.hackster.io/LightPro/tft-graphing-bar-charts-185436
void drawScale()
{
  gfx.drawFastVLine(barX, barY, barHeight, SCALECOLOR);                // Vertical Scale Line Left
  gfx.drawFastVLine(barX + barWidth, barY, barHeight, SCALECOLOR);     // Vertical Scale Line Right
  gfx.drawFastHLine(barX, barY, barWidth, SCALECOLOR);                 // Horizantal Scale Top
  gfx.drawFastHLine(barX, barHeight + barY - 1, barWidth, SCALECOLOR); // Horizantal Scale Bottom, subtract 1 from Y
}
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

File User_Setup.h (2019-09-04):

// This is my working setup for the https://github.com/Bodmer/TFT_eSPI library that I spent quite a bit of time on wiring
// since the pin names are different on this board.
// It is for this screen: 1.77 inch 1.8 TFT Color Display Module Breakout SPI ST7735S for Arduino UNO LCD
// https://www.ebay.com/itm/1-77-inch-1-8-TFT-Color-Display-Module-Breakout-SPI-ST7735S-for-Arduino-UNO-LCD/222565215470
//
// Adafruit    SainSmart    TFT_eSPI    ESP8266    Description
//  Names        Names        Pins       Pins
//
//  GND          GND  1                   GND      // Obvious
//  3V3          VCC  2                   3V3      // Obvious
//  SCL          SCK  3      TFT_SCLK     CLK      // Must be CLK when TFT_SPI_OVERLAP is defined
//  MOSI         SDA  4      TFT_MOSI     SD1      // Must be SD1 when TFT_SPI_OVERLAP is defined
//  RESET        RES  5      TFT_RST      RST      // Could be on GND when RST is set to -1
//  D/C          RS   6      TFT_DC        D5      // Could be another open pin
//  TFT_CS       CS   7      TFT_CS        D3      // Must be D3 when TFT_SPI_OVERLAP is defined
//  LITE         LEDA 8                   VIN      // Might need to be on 3.3v but I have been running it on VIN 5v YMMV
//
//
//                            USER DEFINED SETTINGS
//   Set driver type, fonts to be loaded, pins used and SPI control method etc
//
//   See the User_Setup_Select.h file if you wish to be able to define multiple
//   setups and then easily select which setup file is used by the compiler.
//
//   If this file is edited correctly then all the library example sketches should
//   run without the need to make any more changes for a particular hardware setup!
//   Note that some sketches are designed for a particular TFT pixel width/height

// ##################################################################################
//
// Section 1. Call up the right driver file and any options for it
//
// ##################################################################################

// Only define one driver, the other ones must be commented out
// #define ILI9341_DRIVER
#define ST7735_DRIVER // Define additional parameters below for this display
//#define ILI9163_DRIVER     // Define additional parameters below for this display
//#define S6D02A1_DRIVER
//#define RPI_ILI9486_DRIVER // 20MHz maximum SPI
//#define HX8357D_DRIVER
//#define ILI9481_DRIVER
//#define ILI9486_DRIVER
//#define ILI9488_DRIVER     // WARNING: Do not connect ILI9488 display SDO to MISO if other devices share the SPI bus (TFT SDO does NOT tristate when CS is high)
//#define ST7789_DRIVER      // Full configuration option, define additional parameters below for this display
//#define ST7789_2_DRIVER    // Minimal configuration option, define additional parameters below for this display
//#define R61581_DRIVER
//#define RM68140_DRIVER

// Some displays support SPI reads via the MISO pin, other displays have a single
// bi-directional SDA pin and the library will try to read this via the MOSI line.
// To use the SDA line for reading data from the TFT uncomment the following line:

// #define TFT_SDA_READ      // This option is for ESP32 ONLY, tested with ST7789 display only

// For ST7789 ONLY, define the colour order IF the blue and red are swapped on your display
// Try ONE option at a time to find the correct colour order for your display

//  #define TFT_RGB_ORDER TFT_RGB  // Colour order Red-Green-Blue
//  #define TFT_RGB_ORDER TFT_BGR  // Colour order Blue-Green-Red

// For M5Stack ESP32 module with integrated ILI9341 display ONLY, remove // in line below

// #define M5STACK

// For ST7789, ST7735 and ILI9163 ONLY, define the pixel width and height in portrait orientation
// #define TFT_WIDTH  80
#define TFT_WIDTH 128
// #define TFT_WIDTH  240 // ST7789 240 x 240 and 240 x 320
#define TFT_HEIGHT 160
// #define TFT_HEIGHT 128
// #define TFT_HEIGHT 240 // ST7789 240 x 240
// #define TFT_HEIGHT 320 // ST7789 240 x 320

// For ST7735 ONLY, define the type of display, originally this was based on the
// colour of the tab on the screen protector film but this is not always true, so try
// out the different options below if the screen does not display graphics correctly,
// e.g. colours wrong, mirror images, or tray pixels at the edges.
// Comment out ALL BUT ONE of these options for a ST7735 display driver, save this
// this User_Setup file, then rebuild and upload the sketch to the board again:

// #define ST7735_INITB
// #define ST7735_GREENTAB
// #define ST7735_GREENTAB2
// #define ST7735_GREENTAB3
// #define ST7735_GREENTAB128    // For 128 x 128 display
// #define ST7735_GREENTAB160x80 // For 160 x 80 display (BGR, inverted, 26 offset)
// #define ST7735_REDTAB
#define ST7735_BLACKTAB
// #define ST7735_REDTAB160x80   // For 160 x 80 display with 24 pixel offset

// If colours are inverted (white shows as black) then uncomment one of the next
// 2 lines try both options, one of the options should correct the inversion.

// #define TFT_INVERSION_ON
// #define TFT_INVERSION_OFF

// If a backlight control signal is available then define the TFT_BL pin in Section 2
// below. The backlight will be turned ON when tft.begin() is called, but the library
// needs to know if the LEDs are ON with the pin HIGH or LOW. If the LEDs are to be
// driven with a PWM signal or turned OFF/ON then this must be handled by the user
// sketch. e.g. with digitalWrite(TFT_BL, LOW);

// #define TFT_BACKLIGHT_ON HIGH  // HIGH or LOW are options

// ##################################################################################
//
// Section 2. Define the pins that are used to interface with the display here
//
// ##################################################################################
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

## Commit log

2019-03-30 Update PowderHopperGauge.ino
    Added the switch case in loop() to overwrite the ArduinoMenu and edit the alertPercent and grainPerMM variables in their own larger window.
2019-08-29 Add libraries
    This can't be the easiest way, but in order to preserve the current libraries and my changes, these are the libraries needed.
    [Configuring options.txt]
2019-09-04 Update User_Setup.h
    Updated for TFT_SPI_OVERLAP pin definitions and more clear comments
2019-09-04 Update PowderHopperGauge.ino
    Removed keyIn, removed custom menu that was causing issues, changed button presses to ClickEncoder library with double click turned off, switched to Timer.h for polling, took out SPI.h.
    [PowderHopperGauge.ino]
2019-09-04 Update README.md
    Libraries and firmware.bin, began updating information on rotary encoders.
2019-09-04 Rotary encoder photos
    Photos of rotary encoder styles
2019-09-04 Removed folders fro zip files
    [Configuring options.txt]
2019-09-04 Moved files into folders
    [Bottom V1.3.stl, Cover V1.3.stl, Main Body V1.3.stl]
2019-09-04 Added Dillon STLs
    [Dillon_Bottom_V1.stl, Dillon_Main_Body_V1.1.stl, Dillon_Screw_on_Cover_V1.stl]
2019-09-09 Polarity on VL6180X description was reversed. Made it hot and smell funny.
    [PowderHopperGauge.ino]
2019-10-10 Fixed pin definitions for rotary encoder
    [PowderHopperGauge.ino]
2019-10-11 Making Alarm buzzer configurable via menu
    [PowderHopperGauge.ino]
2019-10-26 Added models with holes for optional buzzers
    [Dillon Main Body with Buzzer V1.4.stl, Hornady Main Body with Buzzer V1.4.stl]
2022-02-22 Update README.md
    Add information about the esp8266 board version needing to be 2.7.3
